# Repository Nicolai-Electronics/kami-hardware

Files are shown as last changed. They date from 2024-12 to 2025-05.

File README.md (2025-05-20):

# Kami: a simple epaper badge

Kami is a modernized re-imagining of the SHA2017 epaper badge by Badge.Team.

## Documentation

Need the schematic? [It's in this repository as a PDF file](schematic.pdf).

## License

This hardware design may be used under the terms of the [CERN-OHL-P](LICENSE) license.

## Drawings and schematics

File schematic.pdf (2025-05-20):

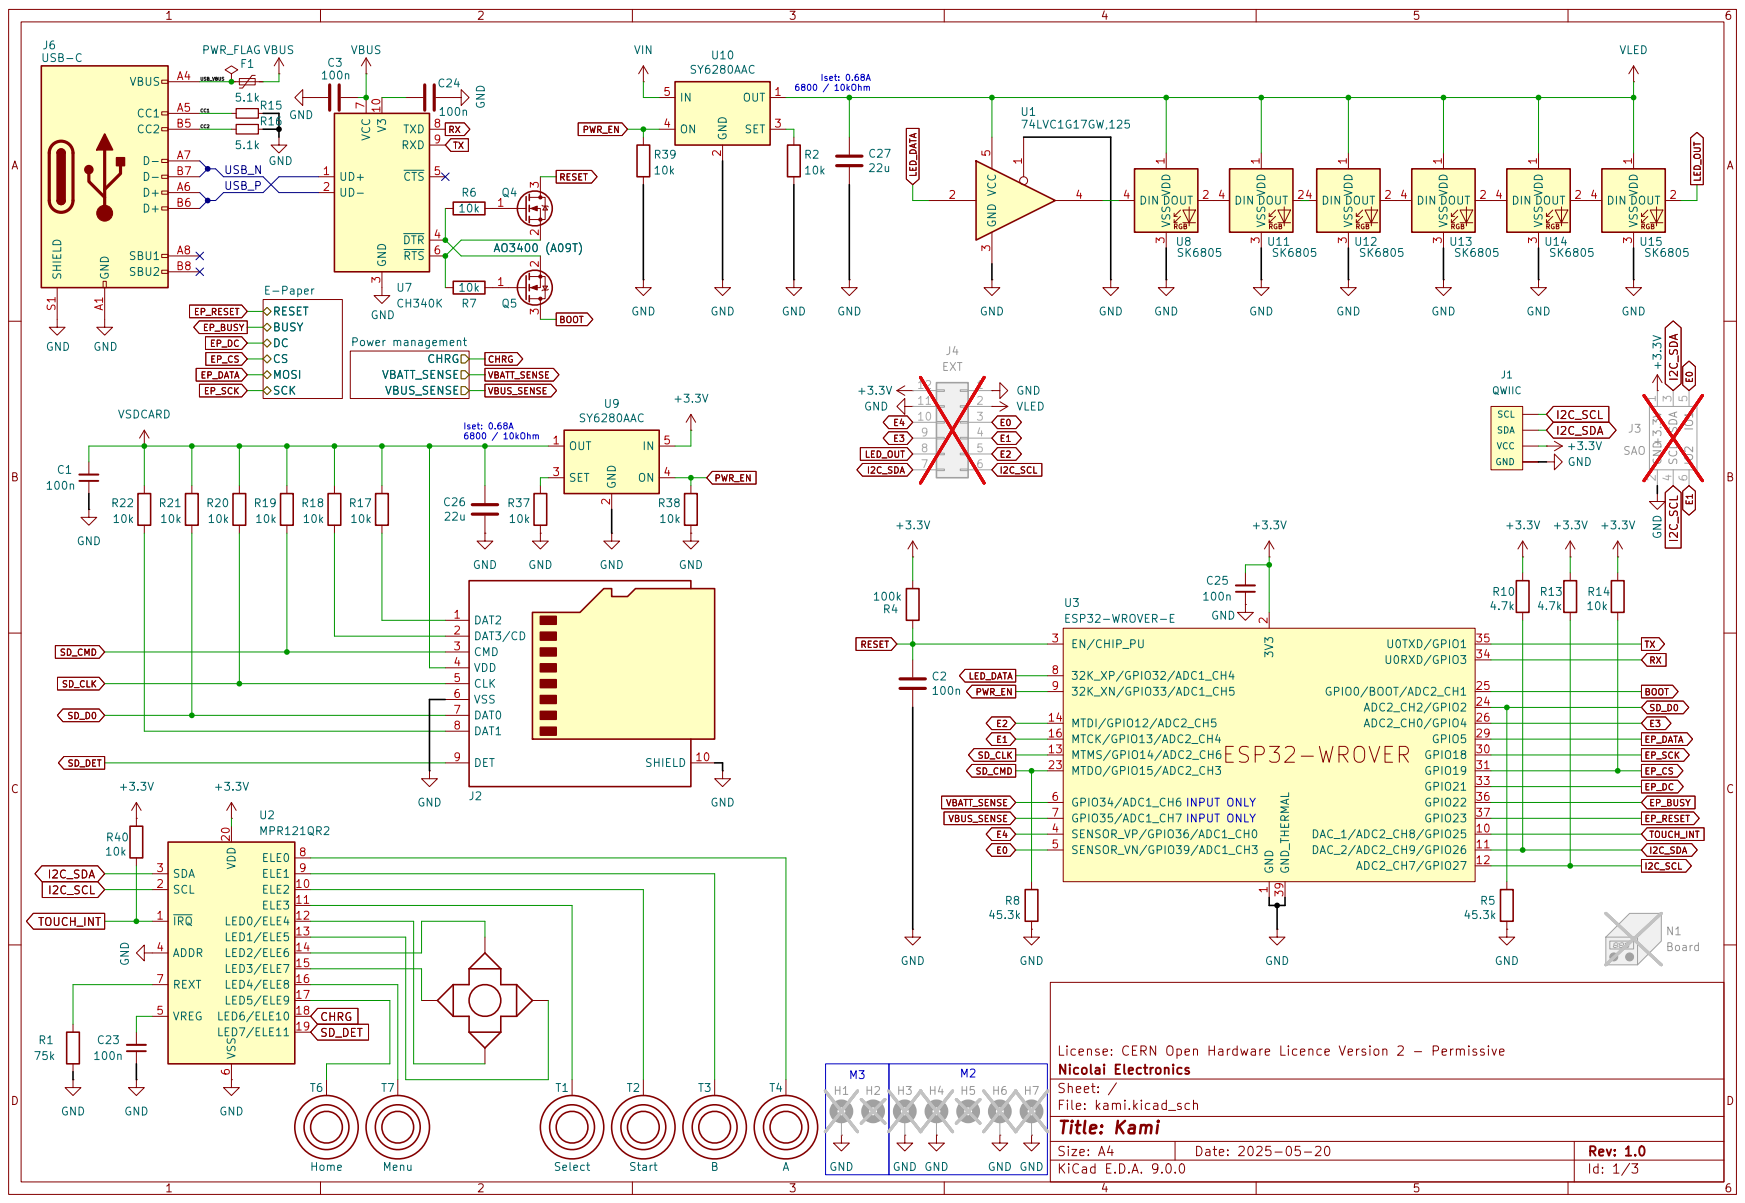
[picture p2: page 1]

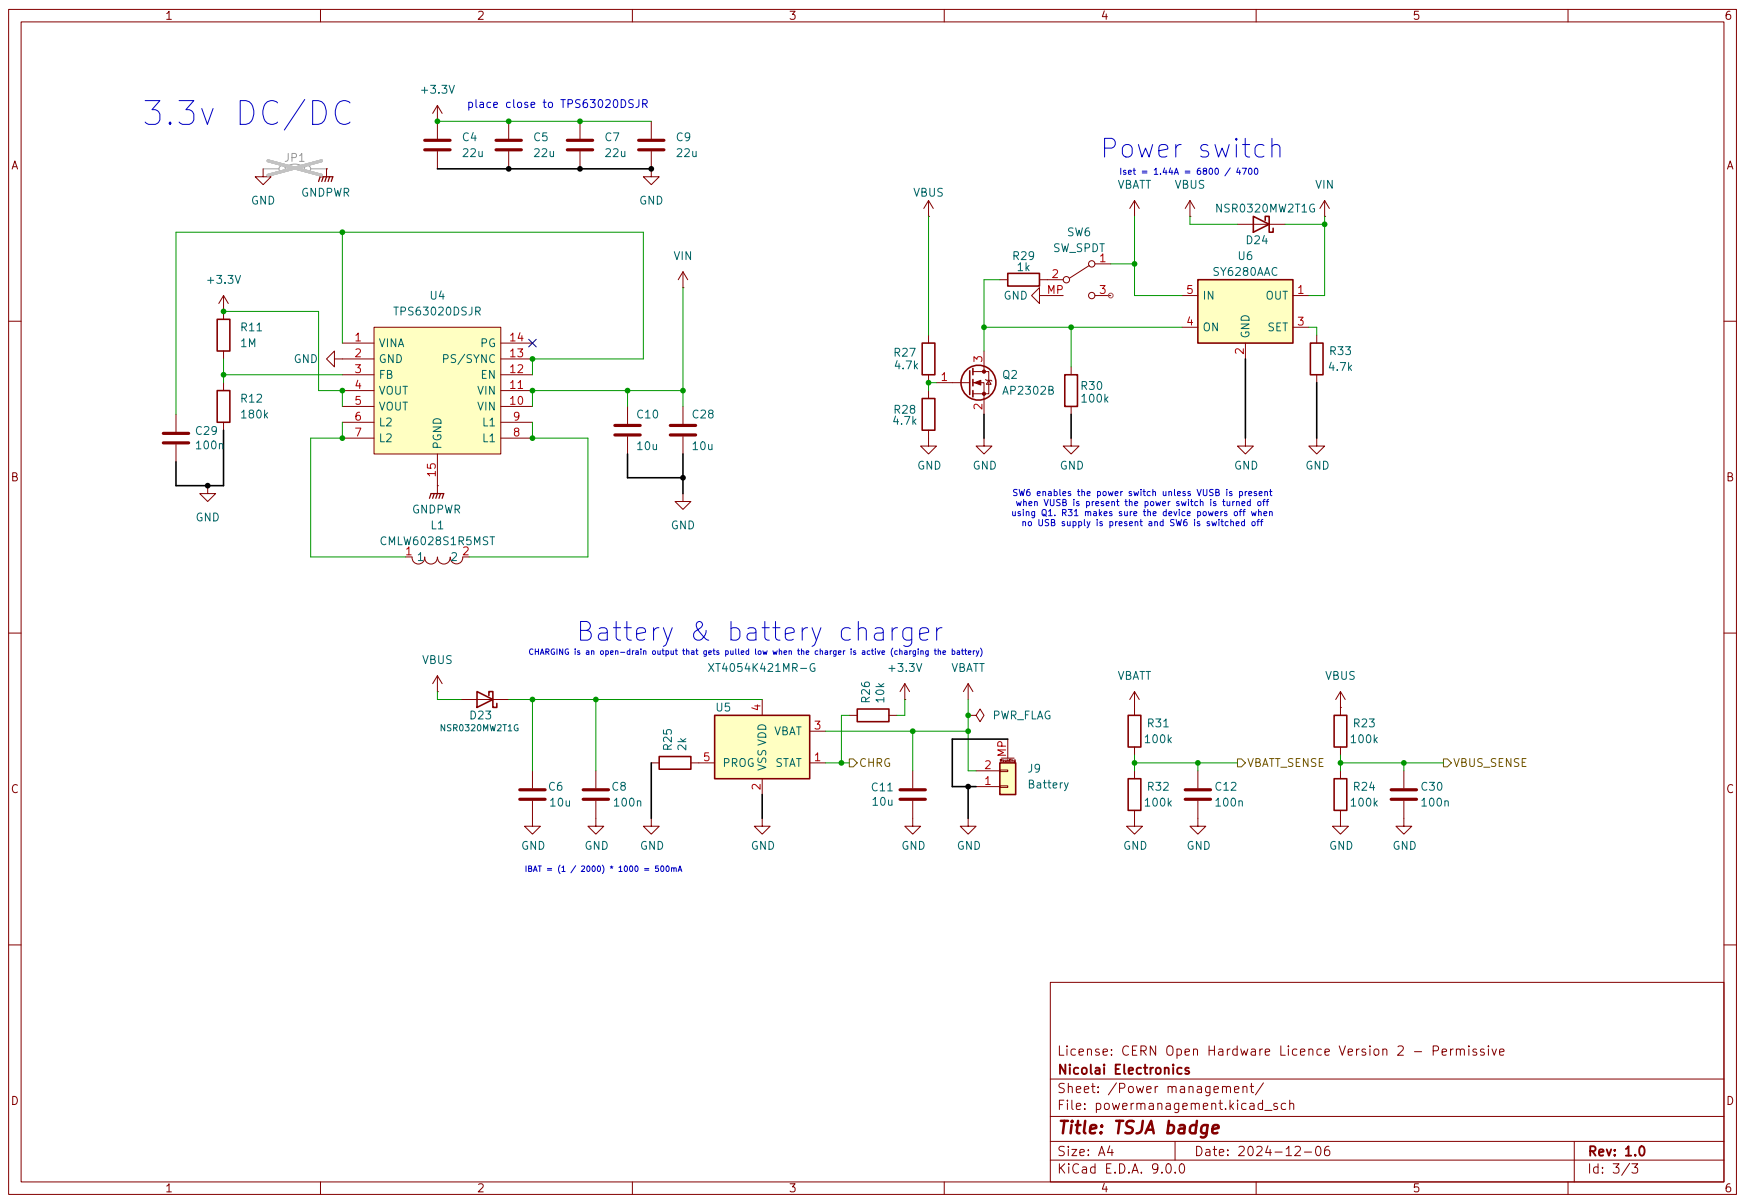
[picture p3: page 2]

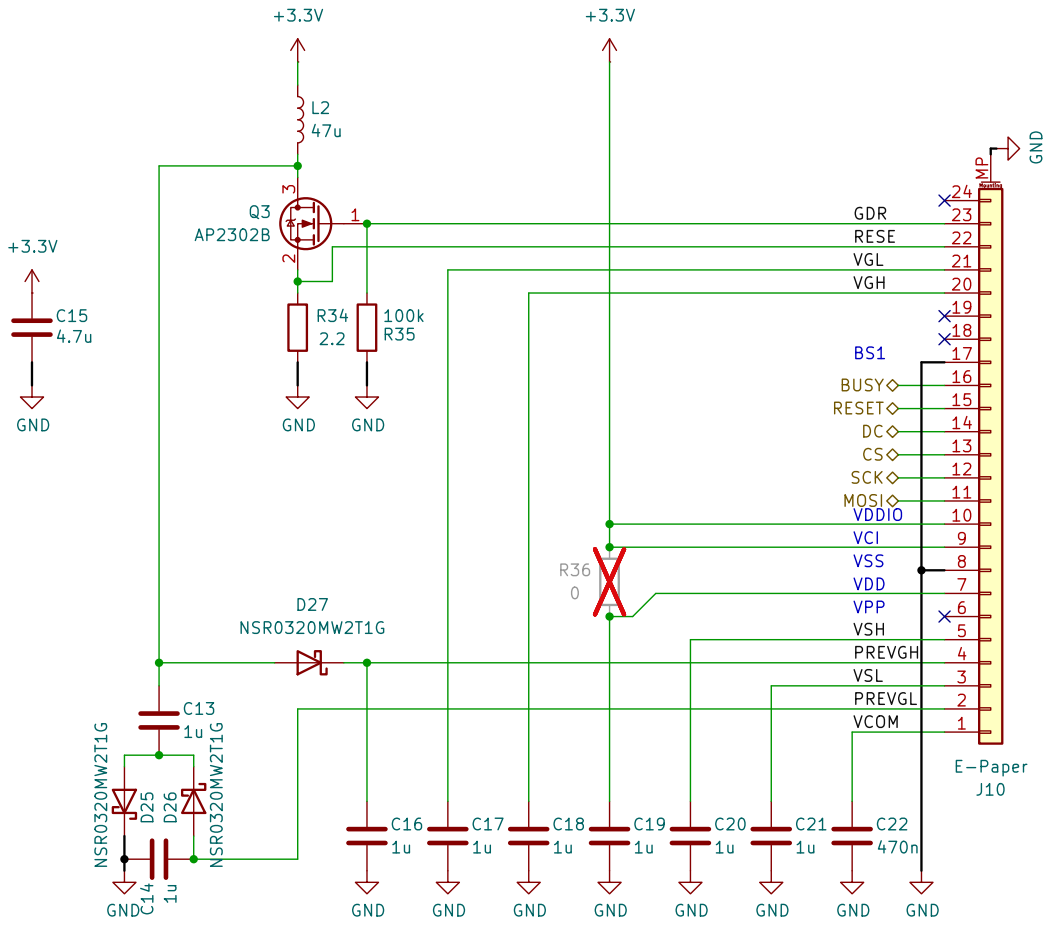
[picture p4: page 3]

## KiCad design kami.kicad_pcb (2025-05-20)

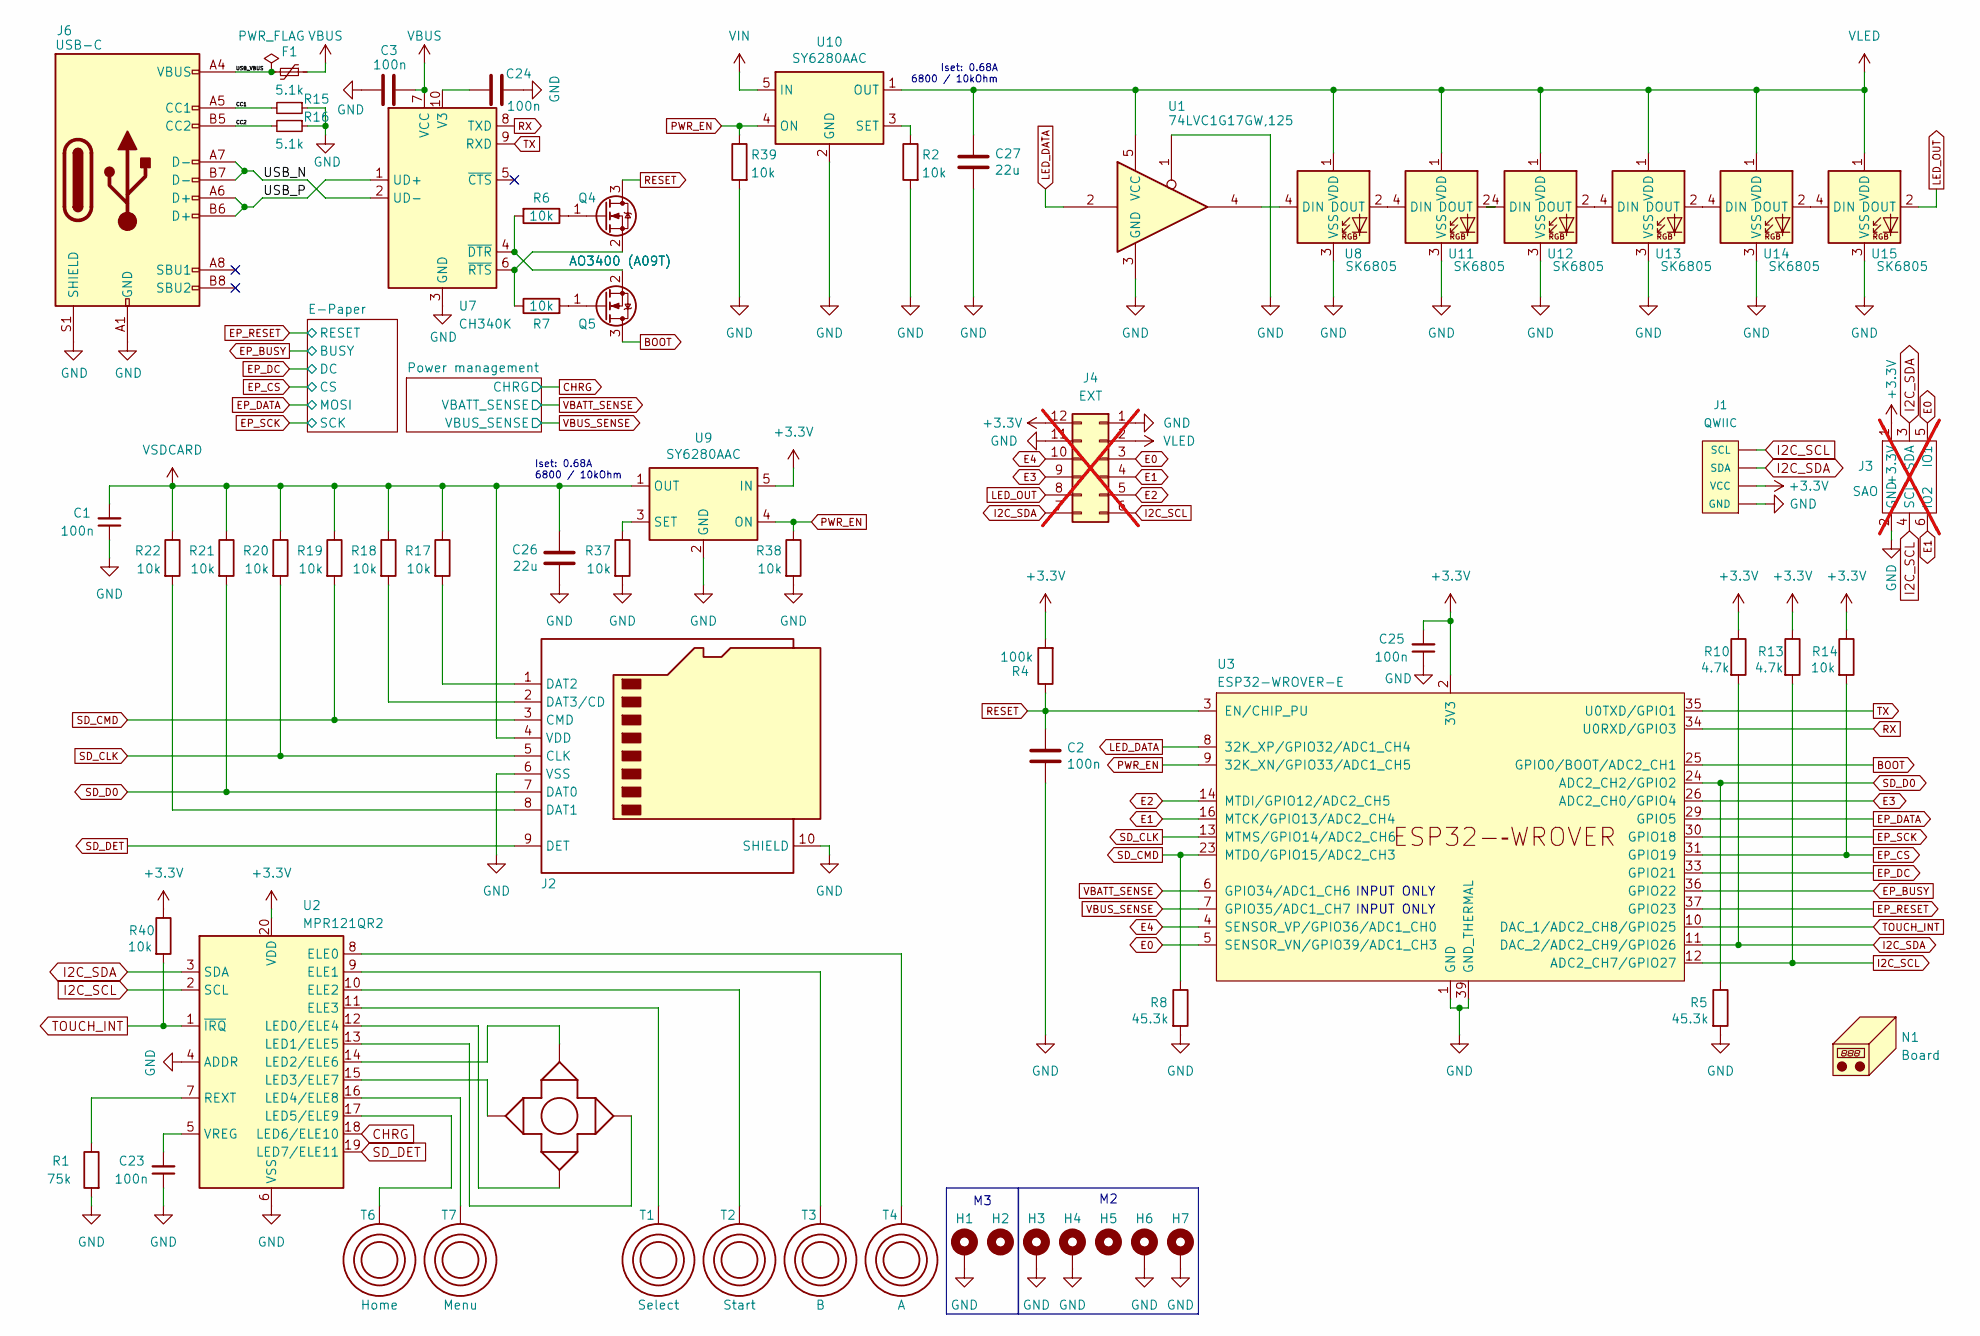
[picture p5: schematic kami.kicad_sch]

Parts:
C1, C2, C3, C23, C24, C25: 100n; C_0402_1005Metric; LCSC C307331
C26, C27: 22u; C_0805_2012Metric; LCSC C45783
F1: 1A; Fuse_0805_2012Metric; LCSC C269107
H1: MountingHole_3.2mm_M3_DIN965_Pad_TopOnly
H2: MountingHole_3.2mm_M3_DIN965
H3, H4, H6, H7: MountingHole_2.7mm_M2.5_Pad_TopOnly
H5: MountingHole_2.7mm_M2.5_DIN965
J1: QWIIC; Qwiic 1X04_1MM_RA_GND; LCSC C160404
J2: Micro_SD_Card; SD_Card-micro_socket_A; LCSC C7529389
J3: SAO; SAO Female THT Labels; LCSC C2829893; not fitted
J4: EXT; EXPANSION; not fitted
J6: USB-C; USB_C_Receptacle_HRO_TYPE-C-31-M-12; LCSC C165948
N1: Board; board
Q4, Q5: AO3400 (A09T); SOT-23; LCSC C2938367
R1: 75k; R_0402_1005Metric; LCSC C25798
R2, R6, R7, R14, R17, R18, R19, R20, R21, R22, R37, R38, R39, R40: 10k; R_0402_1005Metric; LCSC C25744
R4: 100k; R_0402_1005Metric; LCSC C25741
R5, R8: 45.3k; R_0402_1005Metric; LCSC C26980
R10, R13: 4.7k; R_0402_1005Metric; LCSC C25940
R15, R16: 5.1k; R_0402_1005Metric; LCSC C25905
T1: Select; TOUCH_SELECT
T2: Start; TOUCH_SELECT
T3: B; TOUCH_BUTTON
T4: A; TOUCH_BUTTON
T5: Cross; TOUCH_CROSS
T6: Home; home
T7: Menu; menu
U1: 74LVC1G17GW,125; SOT-353_SC-70-5; LCSC C426705
U2: MPR121QR2; UQFN-20_3x3mm_P0.4mm; LCSC C91322
U3: ESP32-WROVER-E; LCSC C529589
U7: CH340K; SSOP-10-1EP_3.9x4.9mm_P1mm_EP2.1x3.3mm; LCSC C18208922
U8, U11, U12, U13, U14, U15: SK6805; SK6805-EC20; LCSC C2890036
U9, U10: SY6280AAC; SOT-23-5; LCSC C55136

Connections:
+3.3V: C25.2, J1.2 (VCC), J3.1 (+3.3V), J4.12, R4.2, R10.1, R13.1, R14.1, R40.1, U2.20 (VDD), U3.2 (3V3), U9.5 (IN); also elsewhere on the board
/CC1: J6.A5 (CC1), R15.2
/CC2: J6.B5 (CC2), R16.2
/USB_N: J6.A7 (D-), J6.B7 (D-), U7.2 (UD-)
/USB_P: J6.A6 (D+), J6.B6 (D+), U7.1 (UD+)
/USB_VBUS: F1.2, J6.A4 (VBUS), J6.A9 (VBUS), J6.B4 (VBUS), J6.B9 (VBUS)
BOOT: Q5.3 (D), U3.25 (GPIO0/BOOT/ADC2_CH1)
CHRG: U2.18 (LED6/ELE10); also elsewhere on the board
E0: J3.5 (IO1), J4.3, U3.5 (SENSOR_VN/GPIO39/ADC1_CH3)
E1: J3.6 (IO2), J4.4, U3.16 (MTCK/GPIO13/ADC2_CH4)
E2: J4.5, U3.14 (MTDI/GPIO12/ADC2_CH5)
E3: J4.9, U3.26 (ADC2_CH0/GPIO4)
E4: J4.10, U3.4 (SENSOR_VP/GPIO36/ADC1_CH0)
EP_BUSY: U3.36 (GPIO22); also elsewhere on the board
EP_CS: R14.2, U3.31 (GPIO19); also elsewhere on the board
EP_DATA: U3.29 (GPIO5); also elsewhere on the board
EP_DC: U3.33 (GPIO21); also elsewhere on the board
EP_RESET: U3.37 (GPIO23); also elsewhere on the board
EP_SCK: U3.30 (GPIO18); also elsewhere on the board
GND: C1.1, C2.2, C3.2, C23.1, C24.2, C25.1, C26.2, C27.2, H1.1, H3.1, H4.1, H6.1, H7.1, J1.1 (GND), J1.5, J1.6, J2.6 (VSS), J2.10 (SHIELD), J3.2 (GND), J4.1, J4.11, J6.A1 (GND), J6.A12 (GND), J6.B1 (GND), J6.B12 (GND), J6.S1 (SHIELD), R1.2, R2.2, R5.2, R8.2, R15.1, R16.1, R37.2, R38.2, R39.2, U1.1, U1.3 (GND), U2.4 (ADDR), U2.6 (VSS), U3.1 (GND), U3.15 (GND), U3.38 (GND), U3.39 (GND_THERMAL), U7.3 (GND), U7.11 (GND), U8.3 (VSS), U9.2 (GND), U10.2 (GND), U11.3 (VSS), U12.3 (VSS), U13.3 (VSS), U14.3 (VSS), U15.3 (VSS); also elsewhere on the board
I2C_SCL: J1.4 (SCL), J3.4 (SCL), J4.6, R13.2, U2.2 (SCL), U3.12 (ADC2_CH7/GPIO27)
I2C_SDA: J1.3 (SDA), J3.3 (SDA), J4.7, R10.2, U2.3 (SDA), U3.11 (DAC_2/ADC2_CH9/GPIO26)
LED_DATA: U1.2, U3.8 (32K_XP/GPIO32/ADC1_CH4)
LED_OUT: J4.8, U15.2 (DOUT)
unnamed: J2.8 (DAT1), R22.2
unnamed: J2.1 (DAT2), R17.2
unnamed: J2.2 (DAT3/CD), R18.2
unnamed: Q4.1 (G), R6.1
unnamed: Q4.2 (S), R7.1, U7.6 (~RTS)
unnamed: Q5.1 (G), R7.2
unnamed: Q5.2 (S), R6.2, U7.4 (~DTR)
unnamed: T4.1, U2.8 (ELE0)
unnamed: T3.1, U2.9 (ELE1)
unnamed: T2.1, U2.10 (ELE2)
unnamed: T1.1, U2.11 (ELE3)
unnamed: T5.3, U2.12 (LED0/ELE4)
unnamed: T5.2, U2.13 (LED1/ELE5)
unnamed: T5.1, U2.14 (LED2/ELE6)
unnamed: T5.4, U2.15 (LED3/ELE7)
unnamed: T7.1, U2.16 (LED4/ELE8)
unnamed: T6.1, U2.17 (LED5/ELE9)
unnamed: R1.1, U2.7 (REXT)
unnamed: C23.2, U2.5 (VREG)
unnamed: C24.1, U7.10 (V3)
unnamed: U1.4, U8.4 (DIN)
unnamed: R37.1, U9.3 (SET)
unnamed: R2.1, U10.3 (SET)
unnamed: U8.2 (DOUT), U11.4 (DIN)
unnamed: U11.2 (DOUT), U12.4 (DIN)
unnamed: U12.2 (DOUT), U13.4 (DIN)
unnamed: U13.2 (DOUT), U14.4 (DIN)
unnamed: U14.2 (DOUT), U15.4 (DIN)
PWR_EN: R38.1, R39.1, U3.9 (32K_XN/GPIO33/ADC1_CH5), U9.4 (ON), U10.4 (ON)
RESET: C2.1, Q4.3 (D), R4.1, U3.3 (EN/CHIP_PU)
RX: U3.34 (U0RXD/GPIO3), U7.8 (TXD)
SD_CLK: J2.5 (CLK), R20.2, U3.13 (MTMS/GPIO14/ADC2_CH6)
SD_CMD: J2.3 (CMD), R8.1, R19.2, U3.23 (MTDO/GPIO15/ADC2_CH3)
SD_D0: J2.7 (DAT0), R5.1, R21.2, U3.24 (ADC2_CH2/GPIO2)
SD_DET: J2.9 (DET), U2.19 (LED7/ELE11)
TOUCH_INT: R40.2, U2.1 (~IRQ), U3.10 (DAC_1/ADC2_CH8/GPIO25)
TX: U3.35 (U0TXD/GPIO1), U7.9 (RXD)
VBATT_SENSE: U3.6 (GPIO34/ADC1_CH6); also elsewhere on the board
VBUS: C3.1, F1.1, U7.7 (VCC); also elsewhere on the board
VBUS_SENSE: U3.7 (GPIO35/ADC1_CH7); also elsewhere on the board
VIN: U10.5 (IN); also elsewhere on the board
VLED: C27.1, J4.2, U1.5 (VCC), U8.1 (VDD), U10.1 (OUT), U11.1 (VDD), U12.1 (VDD), U13.1 (VDD), U14.1 (VDD), U15.1 (VDD)
VSDCARD: C1.2, C26.1, J2.4 (VDD), R17.1, R18.1, R19.1, R20.1, R21.1, R22.1, U9.1 (OUT)

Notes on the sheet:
Iset: 0.68A 6800 / 10kOhm
INPUT ONLY

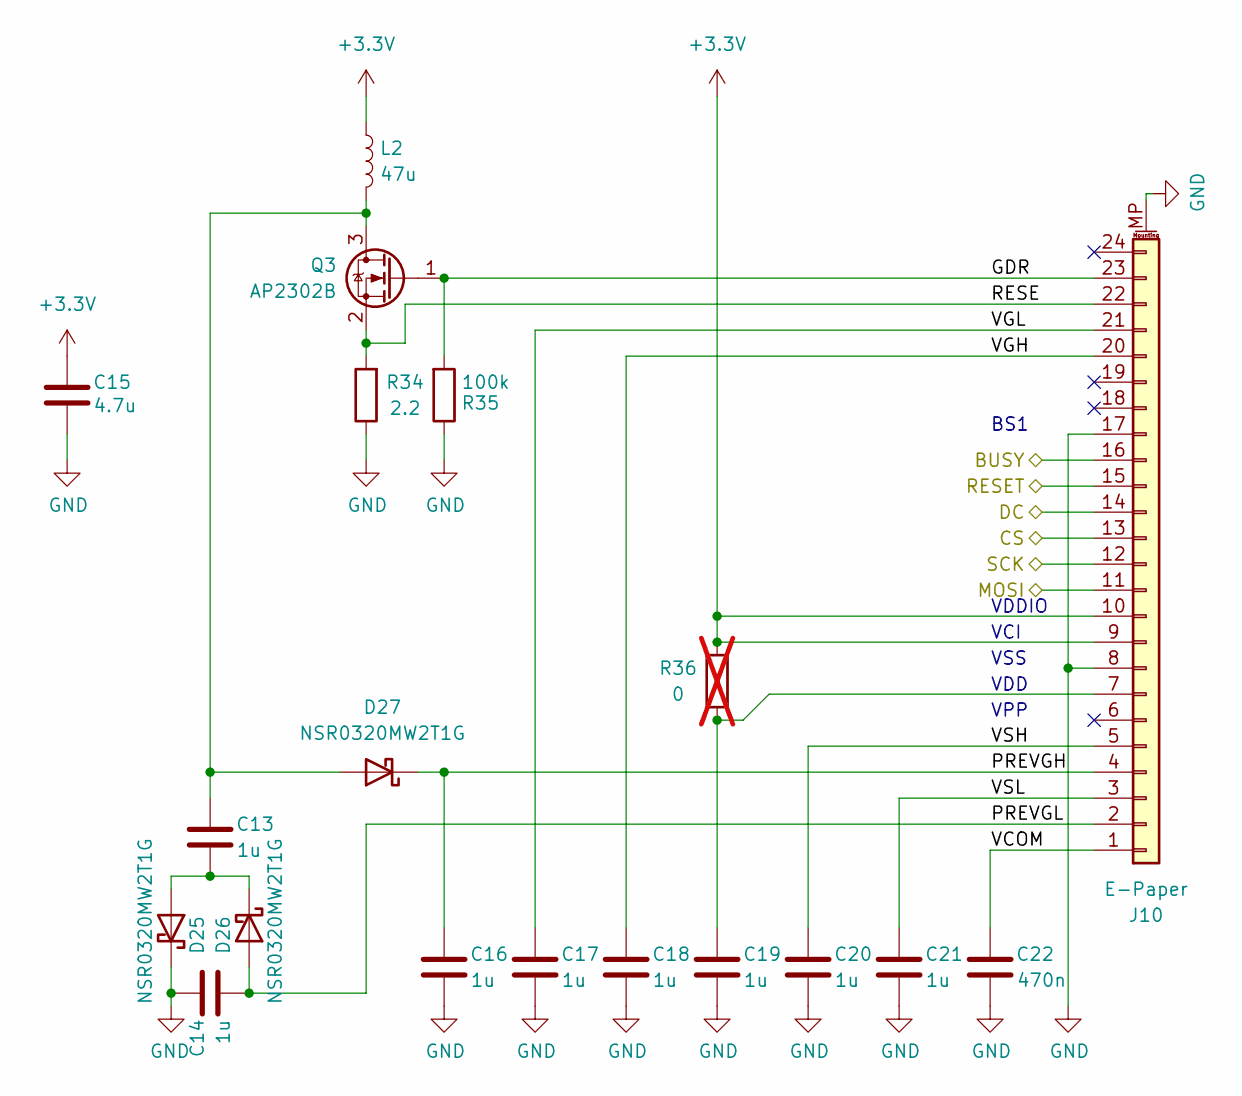
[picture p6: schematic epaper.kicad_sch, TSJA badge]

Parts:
C13, C14, C16, C17, C18, C19, C20, C21: 1u; C_0603_1608Metric; LCSC C5199872
C15: 4.7u; C_0603_1608Metric; LCSC C69335
C22: 470n; C_0603_1608Metric; LCSC C1623
D25, D26, D27: NSR0320MW2T1G; D_SOD-323; LCSC C48192
J10: E-Paper; Hirose_FH12-24S-0.5SH_1x24-1MP_P0.50mm_Horizontal; LCSC C202112
L2: 47u; L_1210_3225Metric; LCSC C83083
Q3: AP2302B; SOT-23; LCSC C406812
R34: 2.2; R_0805_2012Metric; LCSC C2907304
R35: 100k; R_0402_1005Metric; LCSC C25741
R36: 0; R_0402_1005Metric; not fitted

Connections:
+3.3V: C15.2, J10.9, J10.10, L2.1, R36.1; also elsewhere on the board
/E-Paper/GDR: J10.23, Q3.1 (G), R35.2
/E-Paper/PREVGH: C16.2, D27.1 (K), J10.4
/E-Paper/PREVGL: C14.1, D26.2 (A), J10.2
/E-Paper/RESE: J10.22, Q3.2 (S), R34.2
/E-Paper/VCOM: C22.2, J10.1
/E-Paper/VGH: C18.2, J10.20
/E-Paper/VGL: C17.2, J10.21
/E-Paper/VSH: C20.2, J10.5
/E-Paper/VSL: C21.2, J10.3
EP_BUSY: J10.16; also elsewhere on the board
EP_CS: J10.13; also elsewhere on the board
EP_DATA: J10.11; also elsewhere on the board
EP_DC: J10.14; also elsewhere on the board
EP_RESET: J10.15; also elsewhere on the board
EP_SCK: J10.12; also elsewhere on the board
GND: C14.2, C15.1, C16.1, C17.1, C18.1, C19.1, C20.1, C21.1, C22.1, D25.1 (K), J10.8, J10.17, J10.MP (MountPin), R34.1, R35.1; also elsewhere on the board
unnamed: C13.1, D25.2 (A), D26.1 (K)
unnamed: C13.2, D27.2 (A), L2.2, Q3.3 (D)
unnamed: C19.2, J10.7, R36.2

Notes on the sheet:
VDD
VSS
BS1
VDDIO
VCI
VPP

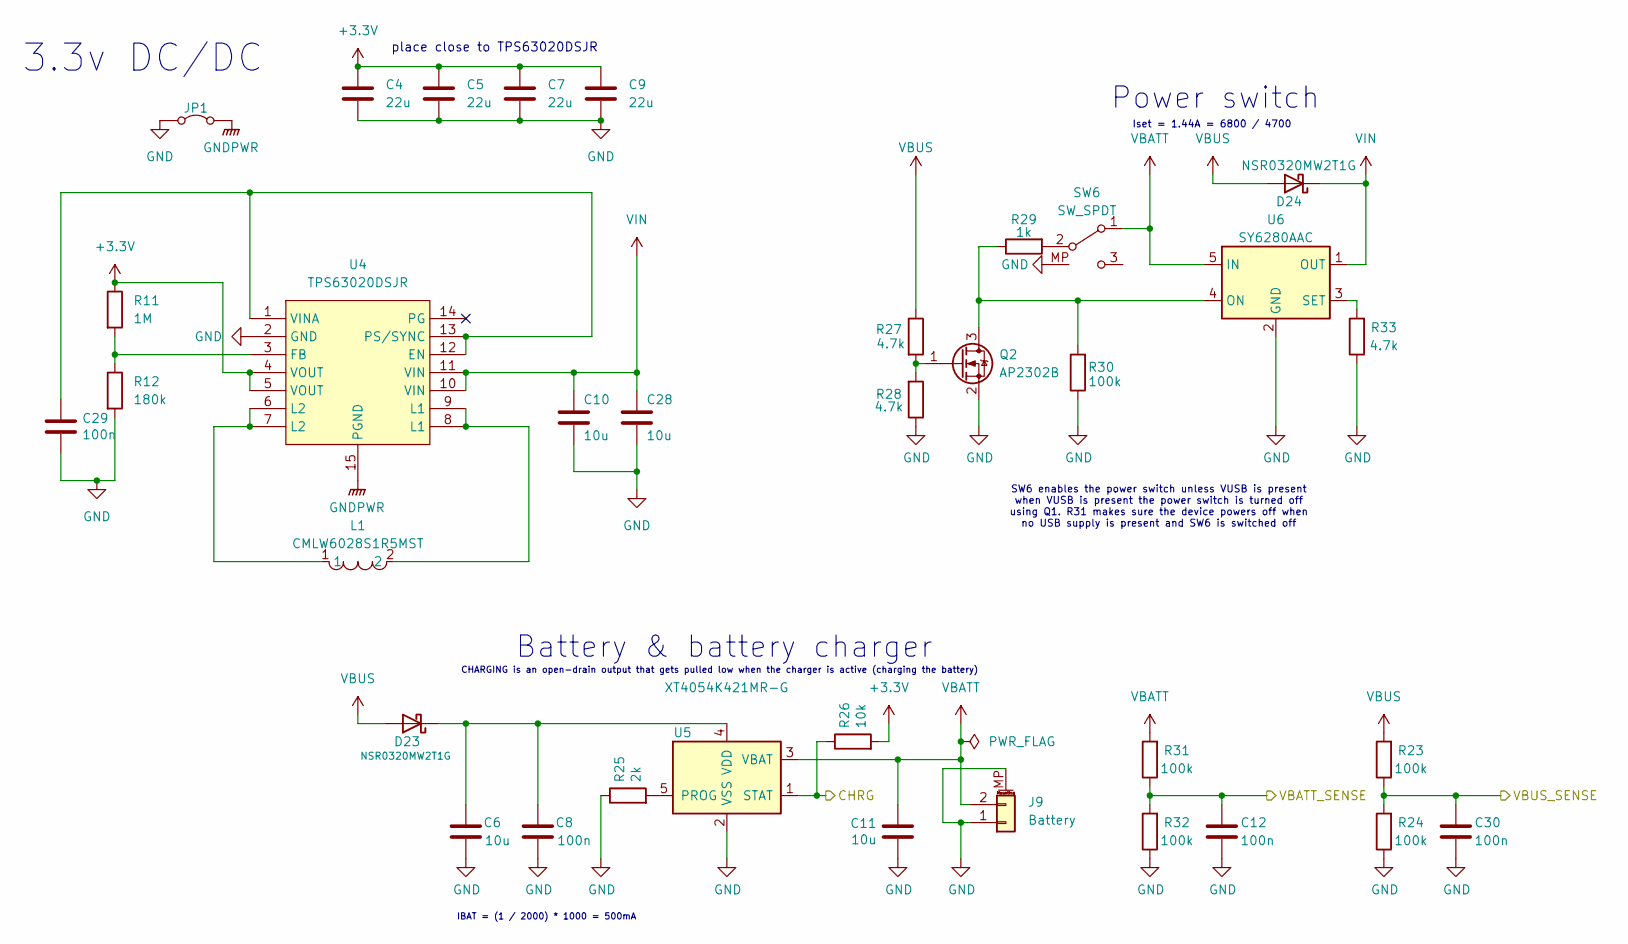
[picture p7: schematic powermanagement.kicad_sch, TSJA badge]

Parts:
C4, C5, C7, C9: 22u; C_0805_2012Metric; LCSC C45783
C6, C10, C11, C28: 10u; C_0805_2012Metric; LCSC C3039694
C8, C12, C29, C30: 100n; C_0402_1005Metric; LCSC C307331
D23, D24: NSR0320MW2T1G; D_SOD-323; LCSC C48192
J9: Battery; JST_S2B-ZR-SM4A-TF(LF)(SN); LCSC C265329
JP1: NetTie-2_SMD_Pad0.5mm
L1: CMLW6028S1R5MST; IND-SMD_L6.0-W6.0; LCSC C431354
Q2: AP2302B; SOT-23; LCSC C406812
R11: 1M; R_0402_1005Metric_Pad0.72x0.64mm_HandSolder; LCSC C26083
R12: 180k; R_0402_1005Metric_Pad0.72x0.64mm_HandSolder; LCSC C2909325
R23, R24, R30, R31, R32: 100k; R_0402_1005Metric; LCSC C25741
R25: 2k; R_0402_1005Metric; LCSC C4109
R26: 10k; R_0402_1005Metric; LCSC C25744
R27, R28, R33: 4.7k; R_0402_1005Metric; LCSC C25940
R29: 1k; R_0402_1005Metric; LCSC C11702
SW6: SW_SPDT; SW_SPDT_PCM12_MP; LCSC C319020
U4: TPS63020DSJR; VSON-14_L4.0-W3.0-P0.50-BL-EP_TI_DSJ; LCSC C15483
U5: XT4054K421MR-G; SOT-23-5; LCSC C141405
U6: SY6280AAC; SOT-23-5; LCSC C55136

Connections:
+3.3V: C4.1, C5.1, C7.1, C9.1, R11.1, R26.2, U4.4 (VOUT), U4.5 (VOUT); also elsewhere on the board
CHRG: R26.1, U5.1 (STAT); also elsewhere on the board
GND: C4.2, C5.2, C6.1, C7.2, C8.1, C9.2, C10.2, C11.2, C12.2, C28.2, C29.2, C30.2, J9.1, J9.MP (MountPin), JP1.1 (A), Q2.2 (S), R12.2, R24.1, R25.1, R28.1, R30.1, R32.1, R33.1, SW6.MP, U4.2 (GND), U5.2 (VSS), U6.2 (GND); also elsewhere on the board
GNDPWR: JP1.2 (B), U4.15 (PGND)
unnamed: C6.2, C8.2, D23.1 (K), U5.4 (VDD)
unnamed: L1.1, U4.6 (L2), U4.7 (L2)
unnamed: L1.2, U4.8 (L1), U4.9 (L1)
unnamed: Q2.3 (D), R29.1, R30.2, U6.4 (ON)
unnamed: Q2.1 (G), R27.2, R28.2
unnamed: R29.2, SW6.2 (B)
unnamed: C29.1, U4.1 (VINA), U4.12 (EN), U4.13 (PS/SYNC)
unnamed: R11.2, R12.1, U4.3 (FB)
unnamed: R25.2, U5.5 (PROG)
unnamed: R33.2, U6.3 (SET)
VBATT: C11.1, J9.2, R31.2, SW6.1 (A), U5.3 (VBAT), U6.5 (IN)
VBATT_SENSE: C12.1, R31.1, R32.2; also elsewhere on the board
VBUS: D23.2 (A), D24.2 (A), R23.2, R27.1; also elsewhere on the board
VBUS_SENSE: C30.1, R23.1, R24.2; also elsewhere on the board
VIN: C10.1, C28.1, D24.1 (K), U4.10 (VIN), U4.11 (VIN), U6.1 (OUT); also elsewhere on the board

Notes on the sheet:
CHARGING is an open-drain output that gets pulled low when the charger is active (charging the battery)
place close to TPS63020DSJR
Power switch
Battery & battery charger
3.3v DC/DC
SW6 enables the power switch unless VUSB is present when VUSB is present the power switch is turned off using Q1. R31 makes sure the device powers off when no USB supply is present and SW6 is switched off
IBAT = (1 / 2000) * 1000 = 500mA
Iset = 1.44A = 6800 / 4700

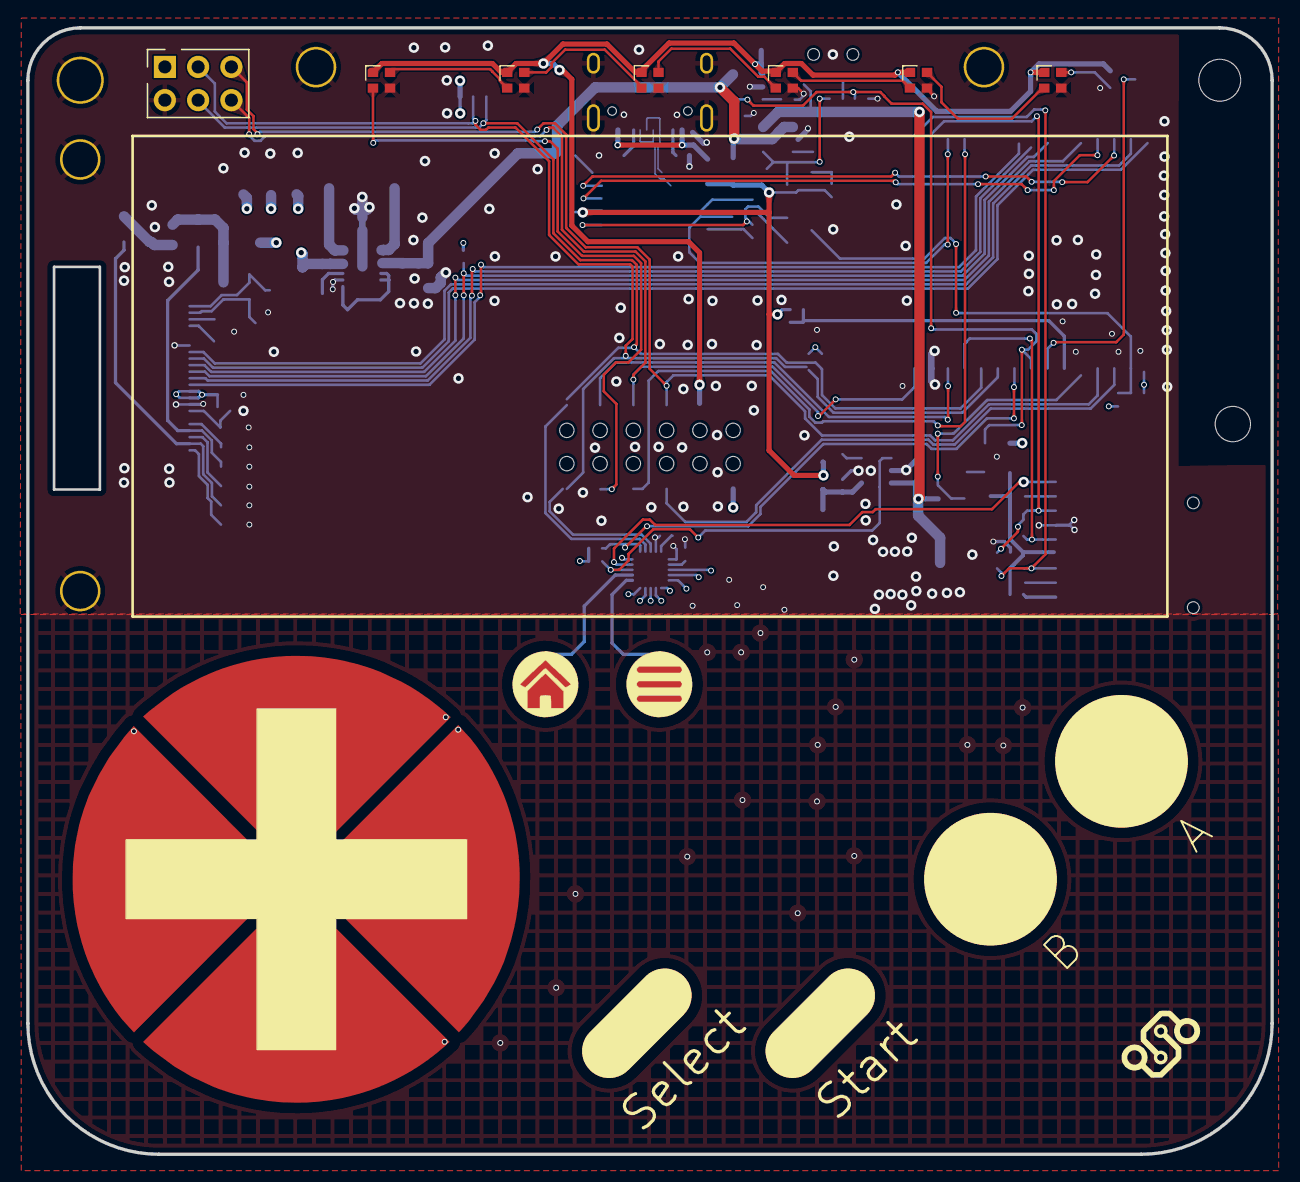
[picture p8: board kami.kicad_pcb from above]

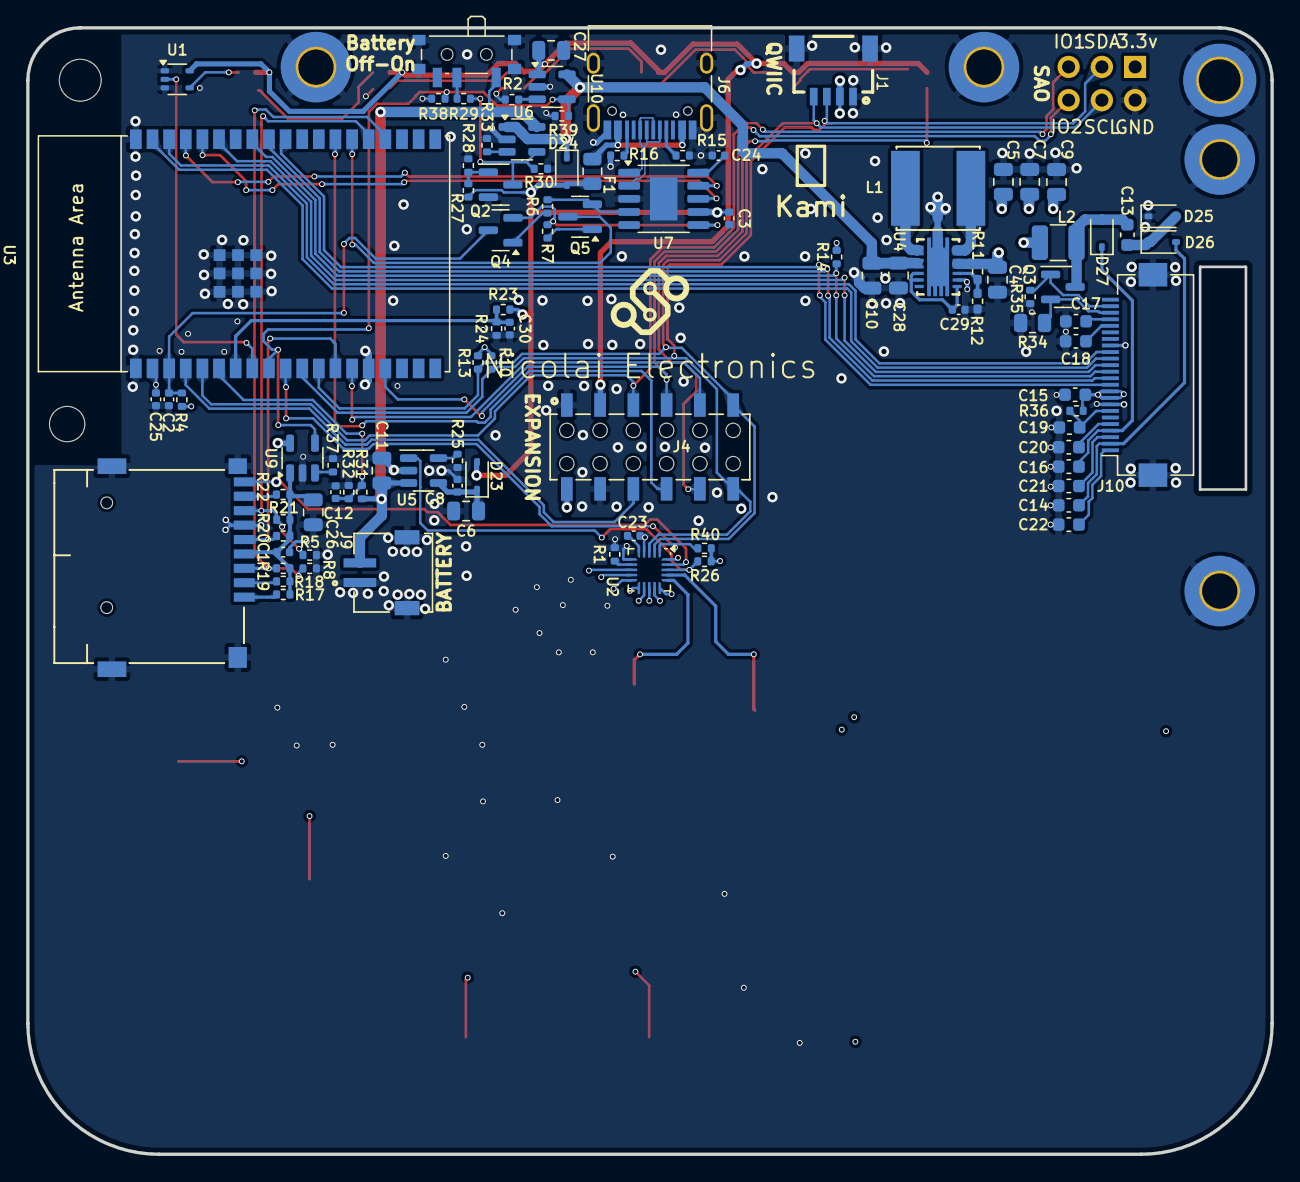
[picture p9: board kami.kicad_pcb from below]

Board: 4 copper layers, 95.0 x 86.0 mm, 118 parts (104 on the bottom side), 91 nets.

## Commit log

2024-12-06 Use DC/DC from WHY badge
    [epaper.kicad_sch, powermanagement.kicad_sch, tsja.kicad_pcb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]
2024-12-07 Small fixes
    [tsja.kicad_pcb, tsja.kicad_sch]
2024-12-08 No DRC errors
    [powermanagement.kicad_sch, tsja.kicad_pcb, tsja.kicad_sch]
2024-12-08 Cleanup & tweaks
    [powermanagement.kicad_sch, tsja.kicad_pcb, tsja.kicad_sch]
2024-12-08 Apply fixes proposed by Paul
    [tsja.kicad_pcb, tsja.kicad_sch]
2024-12-08 Small fix to ground close to R14
    [tsja.kicad_pcb]
2024-12-08 Fill out BOM, add labels to PCB
    [epaper.kicad_sch, powermanagement.kicad_sch, tsja.kicad_pcb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]
2024-12-09 Route captouch traces through inner layer, add two buttons, remove vibration motor
    [tsja.kicad_pcb, tsja.kicad_sch]
2025-05-20 Rename to Kami
    [kami.kicad_pcb, kami.kicad_sch]
2025-05-20 Changes for production version
    [epaper.kicad_sch, kami.kicad_pcb, kami.kicad_sch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]
2025-05-20 Add schematic

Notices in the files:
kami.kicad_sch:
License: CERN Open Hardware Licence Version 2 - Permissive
